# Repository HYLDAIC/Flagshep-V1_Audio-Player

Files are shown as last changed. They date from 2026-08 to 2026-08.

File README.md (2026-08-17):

# Flagshep V1 Audio Player
P1040043
*During Playback*

## Overview
The **Flagshep** is a semi-portable open-source Audio Player designed to provide a reliable, high-quality offline listening experience. It's purpose is to be an alternative to advertisement-ridden subscription based streaming services. The pilot project includes the PCB design files, enclosure CAD models and firmware source code required to build upon, modify or simply take inspiration of the device.

# Features & Specifications 
## Features
- High Quality Audio Diffusion 
- USB-C Charging and Flashing 
## Specifications 
- **Processor :** ESP32 S3 (2 Core 240MHz, 2.4 GHz Wi-Fi 150 Mbps, Bluetooth 5 (LE) )
- **Audio Quality :** PCM5102A ; 16-32bit at 8kHz to 384kHz
- **Flash :** 8MB quad SPI Flash
- **RAM :** 8MB quad SPI SRAM
- **Display :** 0.96in 128x64px OLED TFT display
- **Input :** 6 Button Matrix
- **Storage :** MicroSD card slot
- **Battery :** 5000mAh LiPo with integrated charging and battery management
- **Connectors :** USB Type-C and TRS 3.5mm Audio Jack
- **Dimensions :** 98.7 x 76.8 x 34.7 mm (length-width-height)

# Design 

## Hardware & Included Sensors
- **Microcontroller :** ESP32 S3 Wroom 1
- **DAC Chip :** PCM5102A
- **Battery charging & Protection :** TP4056 & DW01A + FS8205A
- **Voltage Regulator (LDO) :** AP2112K-3.3
- **Battery Percentage Chip :**  MAX17048G+T10
- **Battery Connector :** JST XH-B2B-A


*Logic Depiction of the Hardware*

## Firmware 
- A simple loop that handles button presses, screen refreshes, audio streaming and battery capacity/optimizations; fairly simple
- More coming soon to a town near you!

# Enclosure & Build Instructions (Doesn't include pictures)
- M4 screwdriver
- 3D printed parts (Main, Top of your choosing, and Bottom cover)
- The PCB
- A flat Lithium Polymer battery (LiPo) with the connector JST-XH 2 pin
- 12 6-8mm screws M4 screws
- 12 6x6mm (M4) threaded heated inserts
- Formatted SD Card (FAT32,  exFAT ...) with the audio of your choice (mp3, WAV, FLAC, AAC, m4a)
- A Computer (Linux and or Windows 10-11) with VS Code and Platformio installed
- USB-C Data cable
- Soldering iron

  1. The Main 3D printed part should have prominent holes, 8 on the front side and 4 in the back
  2. Prepare heated element to 250 degrees Celsius (+/- 30)
  3. Place and slowly push in the threaded heated insert with the soldering iron into the hole until the mounting surface is flat (repeat 12 times)
  4. If the battery connector of the PCB isn't on the bottom face (face with no components), solder it on the bottom making sure to keep the same polarities
  5. Insert the SD card in the SD card slot
  6. Take the PCB and insert it inside the side with 8 screws, it should fit with the bottom four; screw it on (it should match with the outside holes on the side of the Main piece)
  7. Insert and screw in the Top cover with 4 screws
  8. Insert a LiPo battery in the bottom compartment and plug it in
  9. Screw in the bottom cover making sure not to break the cable of your battery
  10. Take a USB-C data cable and plug it into the board and the computer
  11. Compile the code given in the Github repo (check tutorials online if you are not sure about how to do this)
  12. Flash the code

# Successes & Future Improvements (Hardware focused)
## Successes
- The audio is smooth and doesn't have noticeable glitching or noise within playback
- A battery life of about 32-40 hours on a 5000mAh battery (~35h of playback in an room varying from 23 to 35 degrees Celsius)
- A smooth user experience; fairly intuitive button mapping, responsive menus and UI (tested by passing my friends the player and receiving feedback)
- An easily accessible and removable battery/screen (4 Screws each)
- Fairly resistant; could be dropped several times with no issues to the PCB (1m drop height)
- The PCB worked first try :)

## Future Improvements
The design has notable failure points that can't be addressed in version 1.1 and would need a more substantial redesign, here are some :
- The circuit drains significant amounts of battery on sleeping parts when the microcontroller is sleeping; physical software activated kill switch needed
- Due to bad design around the battery; the enclosure is huge (height)
- The ESP32 S3 is realistically overkill for the scope of this project AND wireless isn't the focus and could've been avoided
- Components are way too close together making assembly difficult 
- The lack of a knobs proves more difficult than expected
- The screen is really small (this was intended but a more substantial screen could've been afforded under this battery capacity)
- Visible and protruding screws
- Somewhat Heavy (battery)
- The battery percentage chip has interference issues with nearby components and should be placed closer to the battery's connector
- Adding test pads for important signals

Issues that weren't but can be easily addressed in version 1.2 :
- Outside ports are hard to access (too far from outside ridge)
- Thermal relief for ground pads NEED to be added

Personal issues with the design : 
- Many parts of the circuit could have been separated on different boards to permit easy fixing and maintenance (e.g. board 1; power, board 2; logic, etc)

## Plans for the project
Apart from version 1.2, I plan to remake the audio player in a couple of years after I have learned more about circuit design and embedded development.
For now, all the following improvements made to this project will made in the form of sporadic software improvements as I catch problems or wants with the device in my own usage.

# License
The license only applies to the PCB part of the design, not the code nor the 3D STEP files which are unlicensed

# Acknowledgements
## Help & Design inspirations 
- My non-technical friends for support & UX feedback
- r/PrintedCircuits for help with circuit design (https://www.reddit.com/r/PrintedCircuitBoard/)
- PocketMage by Ashtf at Talisman Designs (specs & features section and general design inspiration) (https://www.crowdsupply.com/talisman-design/pocketmage)
## Firmware
- Adafruit (GFX & SSD1306)
- ESP32-audioI2S by Schreibfaul1 (https://github.com/schreibfaul1/ESP32-audioI2S)

## Special Mention
The large reason of why I decided to commit to making this audio player was for my love of music that I'm sure others can relate to.
That said, during the development of the board, one of my favorite band disbanded.
As an homage to them and what their music meant to me, I chose to immortalize them on the surface of my PCB with their most popular instrumental. 
        
          
Again, this is a small tribute, but it may just last forever ;)

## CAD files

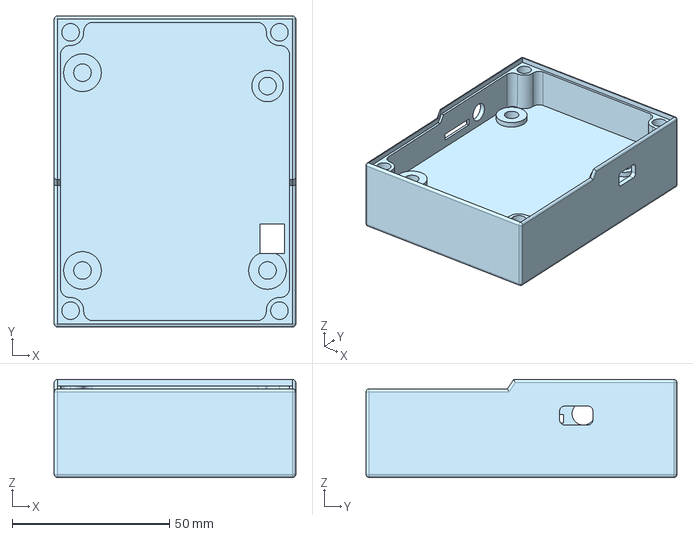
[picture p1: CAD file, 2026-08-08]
CAD/V1.1/CAD/Flagshep Audio Player V1.1 Main.step
76.9 x 99.0 x 31.2 mm

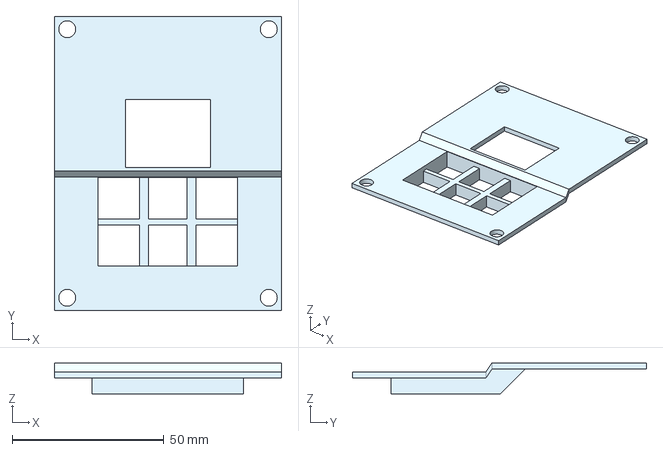
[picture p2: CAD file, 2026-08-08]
CAD/V1.1/CAD/Flagshep Audio Player V1 Top (alt1).step
74.9 x 97.0 x 10.2 mm

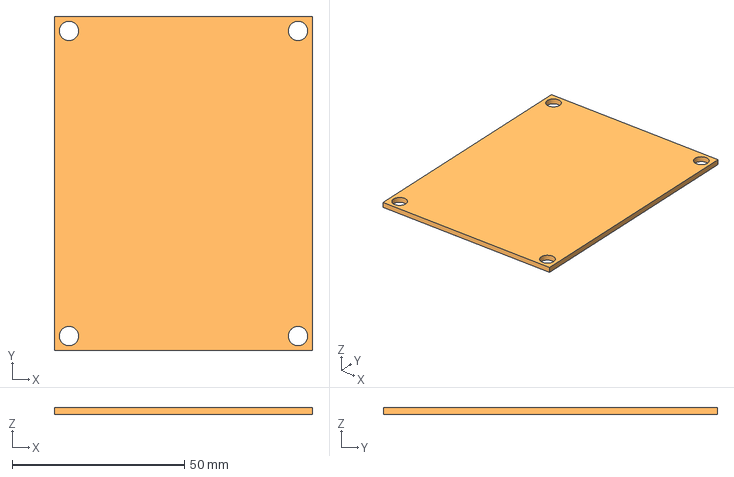
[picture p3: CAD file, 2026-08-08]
CAD/V1.1/CAD/Flagshep Audio Player V1 Bottom.step
74.9 x 97.0 x 2.00 mm

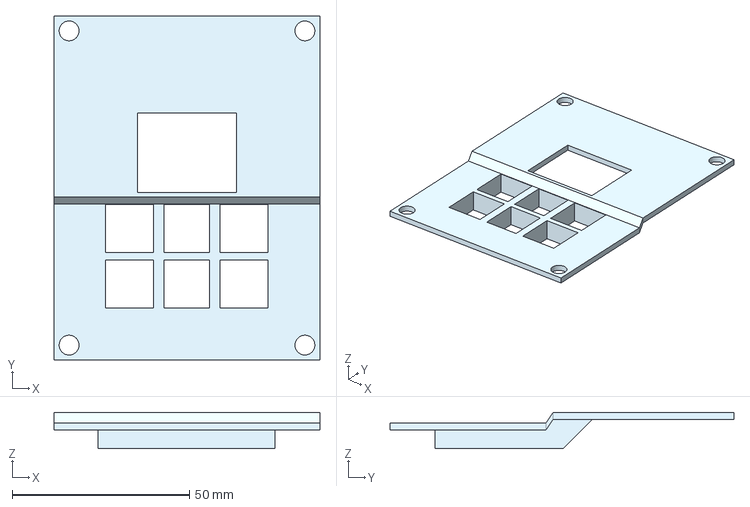
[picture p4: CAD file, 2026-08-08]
CAD/V1.1/CAD/Flagshep Audio Player V1 Top.step
74.9 x 97.0 x 10.2 mm

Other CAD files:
CAD/V1/CAD/Flagshep Audio Player V1 Main.step

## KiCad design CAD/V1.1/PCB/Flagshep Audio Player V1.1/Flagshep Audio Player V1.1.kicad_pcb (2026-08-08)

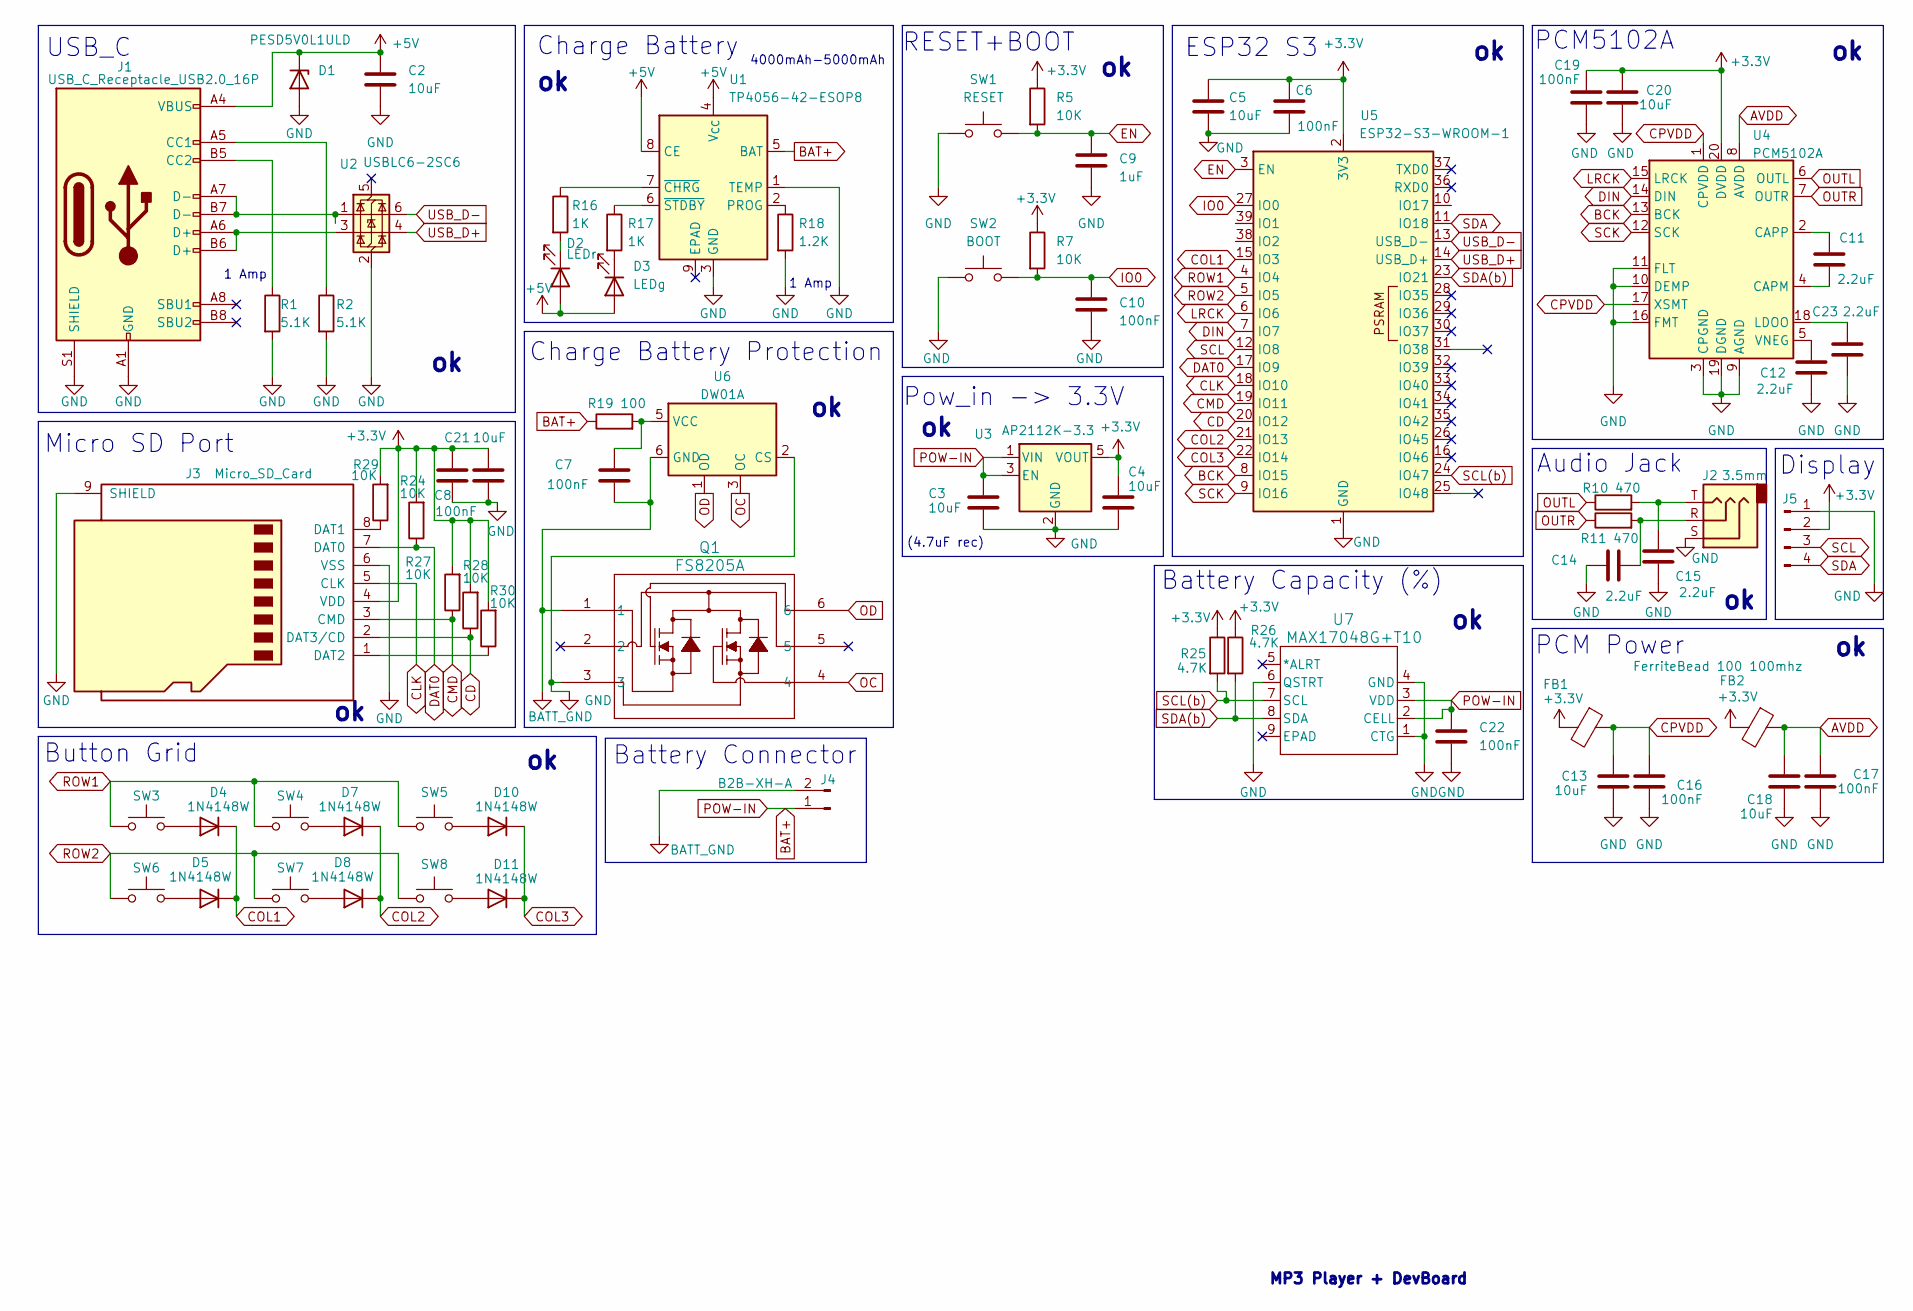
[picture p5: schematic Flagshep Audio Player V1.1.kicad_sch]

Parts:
C2, C13, C18, C20, C21: 10uF; C_0805_2012Metric_Pad1.18x1.45mm_HandSolder
C3, C4, C5: 10uF; R_0805_2012Metric_Pad1.20x1.40mm_HandSolder
C6: 100nF; R_0805_2012Metric_Pad1.20x1.40mm_HandSolder
C7, C8, C10, C16, C17, C19, C22: 100nF; C_0805_2012Metric_Pad1.18x1.45mm_HandSolder
C9: 1uF; R_0805_2012Metric_Pad1.20x1.40mm_HandSolder
C11, C12, C14, C15, C23: 2.2uF; C_0805_2012Metric_Pad1.18x1.45mm_HandSolder
D1: PESD5V0L1ULD; D_SOD-882D
D2: LEDr; LED_1206_3216Metric_Pad1.42x1.75mm_HandSolder
D3: LEDg; LED_1206_3216Metric_Pad1.42x1.75mm_HandSolder
D4, D5, D7, D8, D10, D11: 1N4148W; D_SOD-123
FB1, FB2: FerriteBead 100 100mhz; L_0805_2012Metric_Pad1.15x1.40mm_HandSolder
J1: USB_C_Receptacle_USB2.0_16P; USB_C_Receptacle_G-Switch_GT-USB-7010ASV
J2: 3.5mm; Jack_3.5mm_CUI_SJ-3523-SMT_Horizontal
J3: Micro_SD_Card; microSD_HC_Wuerth_693072010801
J4: B2B-XH-A; JST_XH_B2B-XH-A_1x02_P2.50mm_Vertical
J5: Conn_01x04_Pin; PinHeader_1x04_P2.54mm_Vertical
Q1: FS8205A; SOT-23-6_Handsoldering
R1, R2: 5.1K; R_0805_2012Metric_Pad1.20x1.40mm_HandSolder
R5, R7, R24, R27, R28, R29, R30: 10K; R_0805_2012Metric_Pad1.20x1.40mm_HandSolder
R10, R11: 470; R_0805_2012Metric_Pad1.20x1.40mm_HandSolder
R16, R17: 1K; R_0805_2012Metric_Pad1.20x1.40mm_HandSolder
R18: 1.2K; R_0805_2012Metric_Pad1.20x1.40mm_HandSolder
R19: 100; R_0805_2012Metric_Pad1.20x1.40mm_HandSolder
R25, R26: 4.7K; R_0805_2012Metric_Pad1.20x1.40mm_HandSolder
SW1: RESET; SW_SPST_B3U-1000P
SW2: BOOT; SW_SPST_B3U-1000P
SW3, SW4, SW5, SW6, SW7, SW8: Button_Switch_THT:SW_PUSH-12mm; SW_PUSH-12mm
U1: TP4056-42-ESOP8; SOIC-8-1EP_3.9x4.9mm_P1.27mm_EP2.41x3.3mm_ThermalVias
U2: USBLC6-2SC6; SOT-23-6
U3: AP2112K-3.3; SOT-23-5
U4: PCM5102A; TSSOP-20_4.4x6.5mm_P0.65mm
U5: ESP32-S3-WROOM-1
U6: DW01A; SOT-23-6_Handsoldering
U7: MAX17048G+T10; 21-0168E_T822-3_MXM

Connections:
+3.3V: C4.1, C5.1, C6.1, C8.2, C19.2, C20.2, C21.1, FB1.2, FB2.2, J3.4 (VDD), J5.2, R5.1, R7.1, R24.2, R25.1, R26.1, R27.2, R28.2, R29.2, R30.2, U3.5 (VOUT), U4.20 (DVDD), U5.2 (3V3)
+5V: C2.1, D1.1 (K), D2.2 (A), D3.2 (A), J1.A4 (VBUS), J1.A9 (VBUS), J1.B4 (VBUS), J1.B9 (VBUS), U1.4 (V_{CC}), U1.8 (CE)
AVDD: C17.2, C18.2, FB2.1, U4.8 (AVDD)
BAT+: C3.1, C22.1, J4.1, R19.1, U1.5 (BAT), U3.1 (VIN), U3.3 (EN), U7.2 (CELL), U7.3 (VDD)
BATT_GND: C7.2, J4.2, Q1.1, U6.6 (GND)
BCK: U4.13 (BCK), U5.8 (IO15)
CD: J3.2 (DAT3/CD), R28.1, U5.20 (IO12)
CLK: J3.5 (CLK), U5.18 (IO10)
CMD: J3.3 (CMD), R27.1, U5.19 (IO11)
COL1: D4.1 (K), D5.1 (K), U5.15 (IO3)
COL2: D7.1 (K), D8.1 (K), U5.21 (IO13)
COL3: D10.1 (K), D11.1 (K), U5.22 (IO14)
CPVDD: C13.2, C16.2, FB1.1, U4.1 (CPVDD), U4.17 (XSMT)
DAT0: J3.7 (DAT0), R24.1, U5.17 (IO9)
DIN: U4.14 (DIN), U5.7 (IO7)
EN: C9.1, R5.2, SW1.2, U5.3 (EN)
GND: C2.2, C3.2, C4.2, C5.2, C6.2, C8.1, C9.2, C10.2, C12.2, C13.1, C14.2, C15.2, C16.1, C17.1, C18.1, C19.1, C20.1, C21.2, C22.2, C23.2, D1.2 (A), J1.A1 (GND), J1.A12 (GND), J1.B1 (GND), J1.B12 (GND), J1.S1 (SHIELD), J2.S, J3.6 (VSS), J3.9 (SHIELD), J5.1, Q1.3, R1.2, R2.2, R18.2, SW1.1, SW2.1, U1.1 (TEMP), U1.3 (GND), U2.2 (GND), U3.2 (GND), U4.3 (CPGND), U4.9 (AGND), U4.10 (DEMP), U4.11 (FLT), U4.16 (FMT), U4.19 (DGND), U5.1 (GND), U5.40 (GND), U5.41 (GND), U6.2 (CS), U7.1 (CTG), U7.4 (GND), U7.6 (QSTRT)
IO0: C10.1, R7.2, SW2.2, U5.27 (IO0)
LRCK: U4.15 (LRCK), U5.6 (IO6)
unnamed: C14.1, J2.R, R11.2
unnamed: C15.1, J2.T, R10.2
unnamed: D2.1 (K), R16.2
unnamed: D3.1 (K), R17.2
unnamed: D4.2 (A), SW3.2
unnamed: D5.2 (A), SW6.2
unnamed: D7.2 (A), SW4.2
unnamed: D8.2 (A), SW7.2
unnamed: D10.2 (A), SW5.2
unnamed: D11.2 (A), SW8.2
unnamed: J1.A5 (CC1), R2.1
unnamed: J1.B5 (CC2), R1.1
unnamed: J1.A6 (D+), J1.B6 (D+), U2.3 (I/O2)
unnamed: J1.A7 (D-), J1.B7 (D-), U2.1 (I/O1)
unnamed: J3.8 (DAT1), R29.1
unnamed: J3.1 (DAT2), R30.1
unnamed: R18.1, U1.2 (PROG)
unnamed: R16.1, U1.7 (~CHRG)
unnamed: R17.1, U1.6 (~STDBY)
unnamed: C11.2, U4.4 (CAPM)
unnamed: C11.1, U4.2 (CAPP)
unnamed: C23.1, U4.18 (LDOO)
unnamed: C12.1, U4.5 (VNEG)
unnamed: C7.1, R19.2, U6.5 (VCC)
OC: Q1.4, U6.3 (OC)
OD: Q1.6, U6.1 (OD)
OUTL: R10.1, U4.6 (OUTL)
OUTR: R11.1, U4.7 (OUTR)
ROW1: SW3.1, SW4.1, SW5.1, U5.4 (IO4)
ROW2: SW6.1, SW7.1, SW8.1, U5.5 (IO5)
SCK: U4.12 (SCK), U5.9 (IO16)
SCL: J5.3, U5.12 (IO8)
SCL(b): R25.2, U5.24 (IO47), U7.7 (SCL)
SDA: J5.4, U5.11 (IO18)
SDA(b): R26.2, U5.23 (IO21), U7.8 (SDA)
USB_D+: U2.4 (I/O2), U5.14 (USB_D+)
USB_D-: U2.6 (I/O1), U5.13 (USB_D-)

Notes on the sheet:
ESP32 S3
1 Amp
PCM Power
Charge Battery Protection
PCM5102A
Pow_in -> 3.3V
MP3 Player + DevBoard
Micro SD Port
RESET+BOOT
Battery Capacity (%)
Audio Jack
Battery Connector
Button Grid
Display
4000mAh-5000mAh
Charge Battery
USB_C
(4.7uF rec)

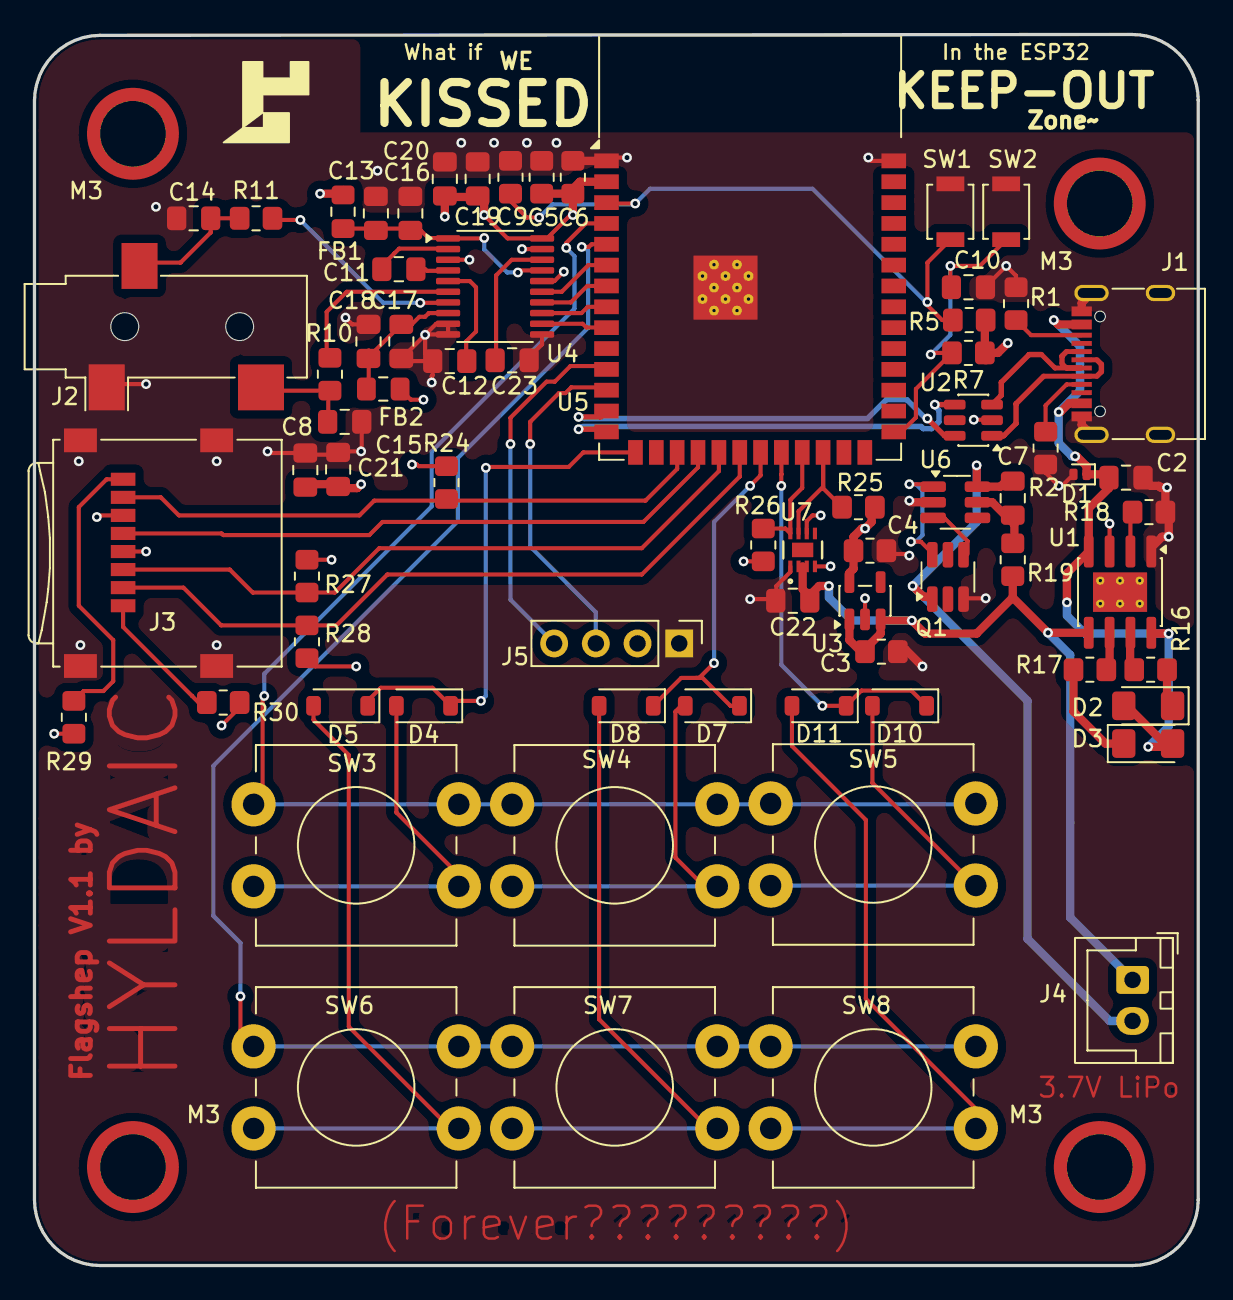
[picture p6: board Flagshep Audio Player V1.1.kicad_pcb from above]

Board: 4 copper layers, 70.9 x 75.0 mm, 73 parts (0 on the bottom side), 56 nets.

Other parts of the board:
M3, M3#2: MountingHole_3.2mm_M3_DIN965_Pad_TopBottom

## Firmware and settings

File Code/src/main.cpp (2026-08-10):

#include <Arduino.h>
#include <SD_MMC.h>
#include <FS.h>
#include <Wire.h>
#include <WiFi.h>
#include <Audio.h>        // ESP32-audioI2S by schreibfaul1
#include <Adafruit_GFX.h>     // Adafruit GFX Library
#include <Adafruit_SSD1306.h> // Adafruit SSD1306 Library
#include "esp_pm.h"
#include "esp_bt.h"
#include "esp_sleep.h"
#include "driver/rtc_io.h"
#include "esp_pm.h"

#define ENABLE_DEBUG_SERIAL 0

#if ENABLE_DEBUG_SERIAL
  #define DBG_BEGIN(baud)   Serial.begin(baud)
  #define DBG_PRINT(x)      Serial.print(x)
  #define DBG_PRINTLN(x)    Serial.println(x)
#else
  #define DBG_BEGIN(baud)
  #define DBG_PRINT(x)
  #define DBG_PRINTLN(x)
#endif

const uint8_t COL1 = 3;
const uint8_t COL2 = 13;
const uint8_t COL3 = 14;
const uint8_t ROW1 = 4;
const uint8_t ROW2 = 5;

const uint8_t ROWS = 2;
const uint8_t COLS = 3;
const uint8_t rowPins[ROWS] = {ROW1, ROW2};
const uint8_t colPins[COLS] = {COL1, COL2, COL3};

void enterDeepSleep();

enum ButtonSlot {
  SLOT_R1C1 = 0,
  SLOT_R1C2,
  SLOT_R1C3,
  SLOT_R2C1,
  SLOT_R2C2,
  SLOT_R2C3      // Switch Menus
};

const ButtonSlot slotMap[ROWS][COLS] = {
  { SLOT_R1C1, SLOT_R1C2, SLOT_R1C3 },
  { SLOT_R2C1, SLOT_R2C2, SLOT_R2C3 }
};

enum MenuScreen {
  MENU_MAIN,       // Normal
  MENU_SECONDARY   // Extras
};

MenuScreen currentMenu = MENU_MAIN;

bool lastRawState[ROWS][COLS];
bool stableState[ROWS][COLS];
unsigned long lastChangeTime[ROWS][COLS];

const uint8_t PCM_LRCK = 6;
const uint8_t PCM_DIN  = 7;
const uint8_t PCM_BCK  = 15;
const uint8_t PCM_SCK  = 16;

const uint8_t BAT_SDA = 21;
const uint8_t BAT_SCL = 47;

TwoWire batteryWire = TwoWire(1);
const uint8_t MAX17048_ADDR = 0x36;
const uint8_t MAX17048_REG_SOC = 0x04; //State-of-charge register

//Intervals 
const unsigned long DEBOUNCE_MS = 30;
const unsigned long BUTTON_SCAN_INTERVAL_MS = 8;
unsigned long lastButtonScanTime = 0;

unsigned long lastBatteryCheckTime = 0;
const unsigned long BATTERY_CHECK_INTERVAL_MS = 10000; //Every 10 sec

unsigned long lastActivityTime = 0;
const unsigned long INACTIVITY_SLEEP_MS = 20000; // 20s idle -> sleep

const unsigned long DISPLAY_UPDATE_INTERVAL_MS = 300;
unsigned long lastDisplayUpdateTime = 0;

float lastBatteryPercent = -1.0f; //-1.0f = no valid reading

const uint8_t TFT_SCL = 8;
const uint8_t TFT_SDA = 18;

#define SCREEN_WIDTH  128
#define SCREEN_HEIGHT 64
#define SCREEN_I2C_ADDR 0x3C

TwoWire displayWire = TwoWire(0);
Adafruit_SSD1306 display(SCREEN_WIDTH, SCREEN_HEIGHT, &displayWire, -1);
bool displayReady = false;

void updateDisplay(bool force = false);

const uint8_t SD_DAT0 = 9;
const uint8_t SD_CLK  = 10;
const uint8_t SD_CMD  = 11;
const uint8_t SD_CD   = 12;

Audio audio;

//Playlist
//Builds and links the playlist back to a text file with all the tracks kept in it, keeps ram usage low
#define MAX_TRACKS 3000
const char *PLAYLIST_FILE_PATH = "/playlist.txt";
uint32_t trackOffsets[MAX_TRACKS]; //Byte offset of the start of each track's line
int trackCount = 0;
int currentTrack = 0;
bool isPlaying = false;
int currentVolume = 15;

File playlistWriteFile; //For building or rebuilding the playlist

//Shuffle bag algorithm 
bool shuffleMode = false;
int shuffleBag[MAX_TRACKS];
int shuffleBagSize = 0;
int shuffleBagPos = 0;
int lastShuffledTrack = -1;

//DEEP SLEEP
RTC_DATA_ATTR int  rtcCurrentTrack  = 0;
RTC_DATA_ATTR int  rtcCurrentVolume = 15;
RTC_DATA_ATTR bool rtcShuffleMode   = false;

//SHUFFLE & DIRECTORY---------------------------------------------------------------------------
void seedRandomOnce() {
  static bool seeded = false;
  if (!seeded) {
    randomSeed(esp_random());
    seeded = true;
  }
}

void refillShuffleBag() {
  seedRandomOnce();
  shuffleBagSize = trackCount;
  for (int i = 0; i < shuffleBagSize; i++) {
    shuffleBag[i] = i;
  }

  //Fisher-Yates shuffle
  for (int i = shuffleBagSize - 1; i > 0; i--) {
    int j = random(0, i + 1);
    int tmp = shuffleBag[i];
    shuffleBag[i] = shuffleBag[j];
    shuffleBag[j] = tmp;
  }

  //Avoid repeating the track that just finished as the very next pick
  if (shuffleBagSize > 1 && shuffleBag[0] == lastShuffledTrack) {
    int swapWith = 1 + (shuffleBagSize > 2 ? random(0, shuffleBagSize - 1) : 0);
    int tmp = shuffleBag[0];
    shuffleBag[0] = shuffleBag[swapWith];
    shuffleBag[swapWith] = tmp;
  }

  shuffleBagPos = 0;
  DBG_PRINTLN("Shuffle bag refilled");
}

int getNextShuffledTrack() {
  if (trackCount == 0) return -1;
  if (shuffleBagSize == 0 || shuffleBagPos >= shuffleBagSize) {
    refillShuffleBag();
  }
  int track = shuffleBag[shuffleBagPos++];
  lastShuffledTrack = track;
  return track;
}

void toggleShuffle() {
  shuffleMode = !shuffleMode;
  if (shuffleMode) {
    //Force a fresh bag whenever shuffle is turned on
    shuffleBagSize = 0;
    DBG_PRINTLN("Shuffle: ON");
  } else {
    DBG_PRINTLN("Shuffle: OFF");
  }
  updateDisplay(true);
}

bool AudioFileType(const String &name) {
  String lower = name;
  lower.toLowerCase();
  return lower.endsWith(".mp3")  ||
         lower.endsWith(".wav")  ||
         lower.endsWith(".flac") ||
         lower.endsWith(".aac")  ||
         lower.endsWith(".m4a");
}

//Recursively walks the SD card and appends every audio file 
void scanDirectory(File dir, const String &path) {
  File entry = dir.openNextFile();
  while (entry) {
    String entryName = entry.name();
    String fullPath;

    if (entryName.startsWith("/")) {
      fullPath = entryName;
    } else {
      fullPath = path + "/" + entryName;
    }

    if (entry.isDirectory()) {
      scanDirectory(entry, fullPath);
    } else {
      if (AudioFileType(fullPath) && trackCount < MAX_TRACKS) {
        trackOffsets[trackCount] = playlistWriteFile.position();
        playlistWriteFile.println(fullPath);
        trackCount++;
        DBG_PRINT("Found: ");
        DBG_PRINTLN(fullPath);
      }
    }
    entry.close();
    entry = dir.openNextFile();
  }
}

//Builds the on-disk playlist file from scratch by scanning the SD
void buildPlaylist() {
  trackCount = 0;

  //FILE_WRITE truncates any existing file, so every rebuild starts from a clean slate
  playlistWriteFile = SD_MMC.open(PLAYLIST_FILE_PATH, FILE_WRITE);
  if (!playlistWriteFile) {
    DBG_PRINTLN("Failed to open playlist file for writing");
    return;
  }

  File root = SD_MMC.open("/");
  if (!root) {
    DBG_PRINTLN("Failed to open root dir");
    playlistWriteFile.close();
    return;
  }
  scanDirectory(root, "");
  root.close();
  playlistWriteFile.close();

  DBG_PRINT("Total tracks found: ");
  DBG_PRINTLN(trackCount);

  // Reset shuffle state whenever the playlist changes
  shuffleBagSize = 0;
  shuffleBagPos = 0;
  lastShuffledTrack = -1;
}

//Looks up a single track's full path on demand by seeking straight to its recorded offset in the playlist file and reading that one line
String getTrackPath(int index) {
  if (index < 0 || index >= trackCount) return String();

  File f = SD_MMC.open(PLAYLIST_FILE_PATH, FILE_READ);
  if (!f) {
    DBG_PRINTLN("Failed to open playlist file for reading");
    return String();
  }

  f.seek(trackOffsets[index]);
  String line = f.readStringUntil('\n');
  f.close();


  while (line.length() > 0 && line.endsWith("\r")) {
    line.remove(line.length() - 1);
  }
  return line;
}

void playTrack(int index);

//Rescans the SD card and rewrites the playlist file, e.g. after songs were added or removed
void rebuildPlaylistRequested() {
  DBG_PRINTLN("Rebuilding playlist...");

  // Immediate on-screen feedback, since a full SD rescan isn't instant.
  if (displayReady) {
    display.clearDisplay();
    display.setTextSize(1);
    display.setTextColor(SSD1306_WHITE);
    display.setCursor(4, 28);
    display.print("Rebuilding playlist...");
    display.display();
  }

  bool wasPlaying = isPlaying;
  String currentPath = (trackCount > 0) ? getTrackPath(currentTrack) : String();

  buildPlaylist();

  int newIndex = 0;
  if (trackCount > 0 && currentPath.length() > 0) {
    for (int i = 0; i < trackCount; i++) {
      if (getTrackPath(i) == currentPath) {
        newIndex = i;
        break;
      }
    }
  }

  if (trackCount == 0) {
    audio.stopSong();
    isPlaying = false;
    currentTrack = 0;
    DBG_PRINTLN("Playlist rebuilt: no tracks found");
  } else {
    currentTrack = newIndex;
    DBG_PRINT("Playlist rebuilt, tracks: ");
    DBG_PRINTLN(trackCount);
    if (wasPlaying) {
      playTrack(currentTrack); // re-attach the file handle after the rescan
    }
  }

  updateDisplay(true);
}

//Re-indexes an existing playlist file by reading straight through it once and recording each line's offset
void loadPlaylistIndexFromFile() {
  trackCount = 0;

  File f = SD_MMC.open(PLAYLIST_FILE_PATH, FILE_READ);
  if (!f) {
    DBG_PRINTLN("No existing playlist file found on wake - a full rebuild is needed");
    return;
  }

  while (f.available() && trackCount < MAX_TRACKS) {
    uint32_t offset = f.position();
    String line = f.readStringUntil('\n');
    if (line.length() == 0) continue; // ignore stray blank/trailing lines
    trackOffsets[trackCount++] = offset;
  }
  f.close();

  DBG_PRINT("Loaded playlist index from file, tracks: ");
  DBG_PRINTLN(trackCount);

  //Reset shuffle state since this is effectively a fresh load
  shuffleBagSize = 0;
  shuffleBagPos = 0;
  lastShuffledTrack = -1;
}

//ACTIONS & BUTTONS------------------------------------------------------------------------
void playTrack(int index) {
  if (trackCount == 0) {
    DBG_PRINTLN("No tracks in playlist");
    return;
  }
  if (index < 0) index = trackCount - 1;
  if (index >= trackCount) index = 0;

  currentTrack = index;
  String path = getTrackPath(currentTrack);
  DBG_PRINT("Playing: ");
  DBG_PRINTLN(path);

  audio.connecttoFS(SD_MMC, path.c_str());
  isPlaying = true;
  updateDisplay(true);
}

void playNext() {
  if (shuffleMode) {
    int idx = getNextShuffledTrack();
    if (idx >= 0) playTrack(idx);
  } else {
    playTrack(currentTrack + 1);
  }
}

void playPrevious() {
  playTrack(currentTrack - 1);
}

void togglePlayPause() {
  if (isPlaying) {
    audio.pauseResume();
    isPlaying = false;
    DBG_PRINTLN("Paused");
  } else {
    audio.pauseResume();
    isPlaying = true;
    DBG_PRINTLN("Resumed");
  }
  updateDisplay(true);
}

void volumeUp() {
  currentVolume = min(21, currentVolume + 1);
  audio.setVolume(currentVolume);
  DBG_PRINT("Volume: ");
  DBG_PRINTLN(currentVolume);
  updateDisplay(true);
}

void volumeDown() {
  currentVolume = max(0, currentVolume - 1);
  audio.setVolume(currentVolume);
  DBG_PRINT("Volume: ");
  DBG_PRINTLN(currentVolume);
  updateDisplay(true);
}

//Menu switching
void toggleMenu() {
  currentMenu = (currentMenu == MENU_MAIN) ? MENU_SECONDARY : MENU_MAIN;
  DBG_PRINT("Menu switched to: ");
  DBG_PRINTLN(currentMenu == MENU_MAIN ? "MAIN" : "SECONDARY");
  updateDisplay(true);
}

//Dispatches a button press according to the slot's physical position and the currently active menu
void handleButtonPress(ButtonSlot slot) {
  if (slot == SLOT_R2C3) {
    toggleMenu();
    return;
  }

  if (currentMenu == MENU_MAIN) {
    switch (slot) {
      case SLOT_R1C1: playPrevious();    break;
      case SLOT_R1C2: togglePlayPause(); break;
      case SLOT_R1C3: playNext();        break;
      case SLOT_R2C1: volumeDown();      break;
      case SLOT_R2C2: volumeUp();        break;
      default: break;
    }
  } else { //MENU_SECONDARY
    switch (slot) {
      case SLOT_R1C1: enterDeepSleep();
      case SLOT_R1C2: break;
      case SLOT_R1C3: break;
      case SLOT_R2C1: toggleShuffle();  break;
      case SLOT_R2C2: rebuildPlaylistRequested();    break;
      default: break;
    }
  }
}

//Non-blocking button matrix with debounce
void setupButtonMatrix() {
  for (uint8_t r = 0; r < ROWS; r++) {
    pinMode(rowPins[r], OUTPUT);
    digitalWrite(rowPins[r], LOW); // idle LOW
  }
  for (uint8_t c = 0; c < COLS; c++) {
    pinMode(colPins[c], INPUT_PULLDOWN); //internal pulldowns (compensates for missing 10K's on the PCB)
  }
  for (uint8_t r = 0; r < ROWS; r++) {
    for (uint8_t c = 0; c < COLS; c++) {
      lastRawState[r][c] = LOW;
      stableState[r][c] = LOW;
      lastChangeTime[r][c] = 0;
    }
  }
}

//Standard button matrix scanning algorithm
void scanButtons() {
  for (uint8_t r = 0; r < ROWS; r++) {
    for (uint8_t rr = 0; rr < ROWS; rr++) {
      digitalWrite(rowPins[rr], rr == r ? HIGH : LOW);
    }
    delayMicroseconds(50); // let signal settle

    for (uint8_t c = 0; c < COLS; c++) {
      bool raw = digitalRead(colPins[c]);

      if (raw != lastRawState[r][c]) {
        lastChangeTime[r][c] = millis();
        lastRawState[r][c] = raw;
      }

      if ((millis() - lastChangeTime[r][c]) > DEBOUNCE_MS) {
        if (raw != stableState[r][c]) {
          stableState[r][c] = raw;

          if (stableState[r][c] == HIGH) {
            lastActivityTime = millis();
            handleButtonPress(slotMap[r][c]);
          }
        }
      }
    }
  }

  // Reset rows back to idle LOW after scan
  for (uint8_t r = 0; r < ROWS; r++) {
    digitalWrite(rowPins[r], LOW);
  }
}

//BATTERY GAUGE (MAX17048G+T10)------------------------------------------------------------
//Reads the SOC register (0x04): high byte = whole percent, low byte = 1/256ths of a percent. Returns -1.0f if the read failed
void batteryQuickStart() {
  batteryWire.beginTransmission(MAX17048_ADDR);
  batteryWire.write(0x06);   // MODE register
  batteryWire.write(0x40);   // QuickStart command, MSB
  batteryWire.write(0x00);   // QuickStart command, LSB
  if (batteryWire.endTransmission() != 0) {
    DBG_PRINTLN("MAX17048 QuickStart write failed (check wiring/address)");
    return;
  }
  delay(10);
}

float readBatteryPercent() {
  batteryWire.beginTransmission(MAX17048_ADDR);
  batteryWire.write(MAX17048_REG_SOC);
  if (batteryWire.endTransmission(false) != 0) { //Repeated start
    return -1.0f;
  }

  uint8_t bytesReceived = batteryWire.requestFrom((int)MAX17048_ADDR, 2);
  if (bytesReceived != 2) {
    return -1.0f;
  }

  uint8_t msb = batteryWire.read();
  uint8_t lsb = batteryWire.read();
  uint16_t raw = ((uint16_t)msb << 8) | lsb;

  return raw / 256.0f;
}

void reportBatteryPercent() {
  float pct = readBatteryPercent();
  if (pct < 0) {
    DBG_PRINTLN("Battery: read error (check MAX17048 wiring/address)");
    return;
  }
  DBG_PRINT("Battery: ");
  DBG_PRINT(pct);
  DBG_PRINTLN("%");

  lastBatteryPercent = pct;
  updateDisplay(true); //Refresh the on-screen battery readout right away
}

void checkBatteryPeriodically() {
  unsigned long now = millis();
  if (now - lastBatteryCheckTime >= BATTERY_CHECK_INTERVAL_MS) {
    lastBatteryCheckTime = now;
    reportBatteryPercent();
  }
}

// DISPLAY (SSD1306 128x64 OLED over I2C)--------------------------------------------------

//Initializes the display
void setupDisplay() {
  displayWire.begin(TFT_SDA, TFT_SCL);

  if (!display.begin(SSD1306_SWITCHCAPVCC, SCREEN_I2C_ADDR)) {
    DBG_PRINTLN("SSD1306 allocation failed (check wiring/address)");
    displayReady = false;
    return;
  }

  displayReady = true;
  display.clearDisplay();
  display.setRotation(2);
  display.setTextColor(SSD1306_WHITE);
  display.setTextWrap(false);
  display.display();
}

//Small battery glyph
void drawBatteryIcon(int x, int y, float pct) {
  const int w = 18, h = 9;
  display.drawRect(x, y, w, h, SSD1306_WHITE);
  display.fillRect(x + w, y + 2, 2, h - 4, SSD1306_WHITE); // terminal tip

  if (pct >= 0) {
    int fillW = map(constrain((int)pct, 0, 100), 0, 100, 0, w - 4);
    if (fillW > 0) {
      display.fillRect(x + 2, y + 2, fillW, h - 4, SSD1306_WHITE);
    }
  } else {
    //No reading yet : draw an "X" through the icon instead
    display.drawLine(x, y, x + w, y + h, SSD1306_WHITE);
    display.drawLine(x, y + h, x + w, y, SSD1306_WHITE);
  }
}

String formatTime(uint32_t totalSeconds) {
  uint32_t m = totalSeconds / 60;
  uint32_t s = totalSeconds % 60;
  String out = String(m) + ":";
  if (s < 10) out += "0";
  out += String(s);
  return out;
}

//Strips the directory path off a full SD path leaving just the filename
String trackDisplayName(const String &path) {
  int slash = path.lastIndexOf('/');
  return (slash >= 0) ? path.substring(slash + 1) : path;
}

//Menu 1: normal playback screen
void drawMainMenuScreen() {
  //Battery percentage + menu indicator
  display.setCursor(0, 0);
  if (lastBatteryPercent >= 0) {
    display.print(lastBatteryPercent);
    display.print('%');
  } else {
    display.print("--%");
  }
  display.setCursor(92, 0);
  display.print("M1");
  drawBatteryIcon(SCREEN_WIDTH - 20, 0, lastBatteryPercent);
  display.drawFastHLine(0, 11, SCREEN_WIDTH, SSD1306_WHITE);

  //Track name (+scroll)
  display.setCursor(0, 18);
  if (trackCount == 0) {
    display.print("No tracks found");
  } else {
    String name = trackDisplayName(getTrackPath(currentTrack));
    const int maxChars = SCREEN_WIDTH / 6;

    if ((int)name.length() > maxChars) {
      static unsigned long lastScrollTime = 0;
      static int scrollOffset = 0;
      static int lastScrollTrack = -1;

      unsigned long now = millis();
      if (lastScrollTrack != currentTrack) {
        //New track -> restart the scroll.
        lastScrollTrack = currentTrack;
        scrollOffset = 0;
        lastScrollTime = now;
      } else if (now - lastScrollTime > 300) {
        lastScrollTime = now;
        scrollOffset++;
        if (scrollOffset > (int)name.length() + 3) scrollOffset = 0;
      }

      String looped = name + "   " + name; // wrap-around buffer
      display.print(looped.substring(scrollOffset, scrollOffset + maxChars));
    } else {
      display.print(name);
    }
  }

  // ---- Track counter ----
  display.setCursor(0, 30);
  display.print("Track ");
  display.print(trackCount > 0 ? currentTrack + 1 : 0);
  display.print('/');
  display.print(trackCount);

  // ---- Playback state + shuffle indicator ----
  display.setCursor(0, 42);
  display.print(isPlaying ? "> Playing" : "|| Paused");
  if (shuffleMode) {
    display.setCursor(SCREEN_WIDTH - 30, 42);
    display.print("SHUF");
  }

  // ---- Volume bar ----
  display.setCursor(0, 54);
  display.print("Vol");
  const int barX = 24, barY = 55, barW = SCREEN_WIDTH - barX, barH = 7;
  display.drawRect(barX, barY, barW, barH, SSD1306_WHITE);
  int filled = map(currentVolume, 0, 21, 0, barW - 2);
  if (filled > 0) {
    display.fillRect(barX + 1, barY + 1, filled, barH - 2, SSD1306_WHITE);
  }
}

//Menu 2: shuffle / rebuild screen / Sleep
void drawSecondaryMenuScreen() {
  display.setCursor(0, 0);
  if (lastBatteryPercent >= 0) {
    display.print(lastBatteryPercent);
    display.print('%');
  } else {
    display.print("--%");
  }

  display.setCursor(92, 0);
  display.print("M2");
  drawBatteryIcon(SCREEN_WIDTH - 20, 0, lastBatteryPercent);
  display.drawFastHLine(0, 11, SCREEN_WIDTH, SSD1306_WHITE);

  display.setCursor(0, 18);
  if (trackCount == 0) {
    display.print("No tracks found");
  } else {
    String name = trackDisplayName(getTrackPath(currentTrack));
    const int maxChars = SCREEN_WIDTH / 6;

    if ((int)name.length() > maxChars) {
      static unsigned long lastScrollTime = 0;
      static int scrollOffset = 0;
      static int lastScrollTrack = -1;

      unsigned long now = millis();
      if (lastScrollTrack != currentTrack) {
        //New track -> restart the scroll
        lastScrollTrack = currentTrack;
        scrollOffset = 0;
        lastScrollTime = now;
      } else if (now - lastScrollTime > 300) {
        lastScrollTime = now;
        scrollOffset++;
        if (scrollOffset > (int)name.length() + 3) scrollOffset = 0;
      }

      String looped = name + "   " + name; // wrap-around buffer
      display.print(looped.substring(scrollOffset, scrollOffset + maxChars));
    } else {
      display.print(name);
    }
  }

  // Elapsed / total time, useful while seeking
  display.setCursor(0, 30);
  if (trackCount > 0) {
    uint32_t elapsed = audio.getAudioCurrentTime();
    uint32_t duration = audio.getAudioFileDuration();
    display.print(formatTime(elapsed));
    display.print(" / ");
    display.print(formatTime(duration));
  } else {
    display.print("--:-- / --:--");
  }

  display.setCursor(0, 42);
  display.print("Enter Deep Sleep");
  display.setCursor(0, 54);
  display.print(shuffleMode ? "SHUF:ON" : "SHUF:OFF");
  display.setCursor(74, 54);
  display.print("REBUILD");
}

// Redraws the whole screen
void updateDisplay(bool force) {
  if (!displayReady) return;

  unsigned long now = millis();
  if (!force && (now - lastDisplayUpdateTime) < DISPLAY_UPDATE_INTERVAL_MS) {
    return;
  }
  lastDisplayUpdateTime = now;

  display.clearDisplay();
  display.setTextSize(1);
  display.setTextColor(SSD1306_WHITE);

  if (currentMenu == MENU_MAIN) {
    drawMainMenuScreen();
  } else {
    drawSecondaryMenuScreen();
  }

  display.display();
}

//POWER MANAGEMENT------------------------------------------------------------------------
//Would enable DFS (dynamic frequency scaling) + automatic light sleep
void setupPowerManagement() {
#if CONFIG_PM_ENABLE
  esp_pm_config_t pm_config = {};
  pm_config.max_freq_mhz = 240;   // burst up for audio decode / SD reads
  pm_config.min_freq_mhz = 80;    // idle down otherwise
  pm_config.light_sleep_enable = true;

  esp_err_t err = esp_pm_configure(&pm_config);
  if (err != ESP_OK) {
    DBG_PRINT("esp_pm_configure failed, err=");
    DBG_PRINTLN((int)err);
  }
#else
  DBG_PRINTLN("CONFIG_PM_ENABLE not compiled in - using manual CPU scaling fallback");
  setCpuFrequencyMhz(240);
#endif
}
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
void loop() {
  audio.loop();

  unsigned long now = millis();
  if (now - lastButtonScanTime >= BUTTON_SCAN_INTERVAL_MS) {
    lastButtonScanTime = now;
    scanButtons();
  }

  checkBatteryPeriodically();
  checkIdleSleep();
  updateManualCpuScaling();
  updateDisplay();
}

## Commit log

2026-08-12 Update README.md
    Added list of required tools and materials for enclosure build.
2026-08-12 Update enclosure and build instructions in README
    Added additional components and instructions for assembly.
2026-08-17 Add license section to README
    Added a section about the license for the PCB design.
